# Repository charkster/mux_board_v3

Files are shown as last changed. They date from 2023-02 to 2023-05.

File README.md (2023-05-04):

# mux_board_v3
Custom PCB with SAMD21 QT PY controlling TWO ADG1606BRUZ 16 input muxes!

**--> UPDATED design available: [mux_board_v5](https://github.com/charkster/mux_board_v5) <--**

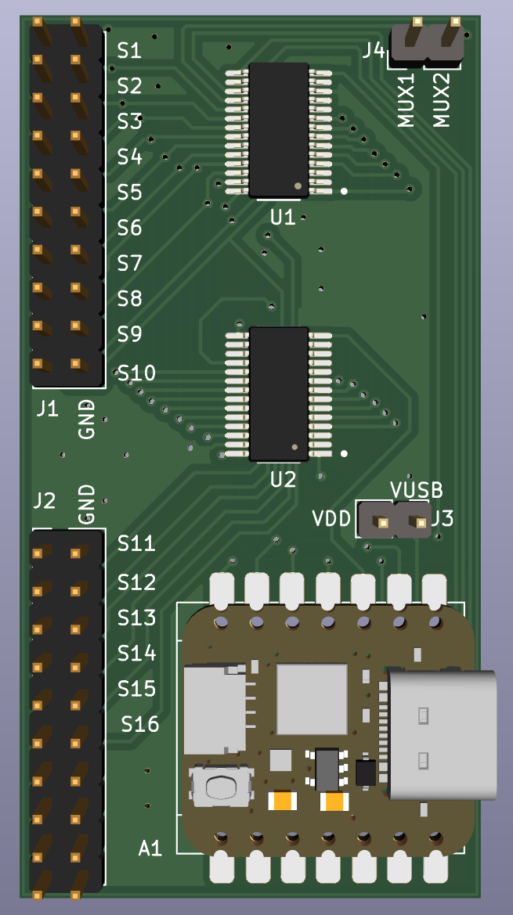
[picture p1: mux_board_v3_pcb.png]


Check-out my **PDF** [schematic](https://github.com/charkster/mux_board_v3/blob/main/mux_board_v3_schematic.pdf) !!

The SAMD21 QT PY can be  programmed with the qt_py_samd21-usbtmc.uf2 file (drag-n-drop) and has the same USBTMC commands that my [Mux Board V1](https://github.com/charkster/mux_board_v1) had. Here is the list:

**MUX1:EN 1** # enable MUX1, a zero will disable the mux

**MUX1:SEL 1** # select S1 input, values 1 through 16 are valid

**MUX1:EN?** # this query returns the state of MUX1

**MUX1:SEL?** # this query returns the presently selected input

***RST** # disables all MUX enables

***IDN?** # returns valid commands and this URL

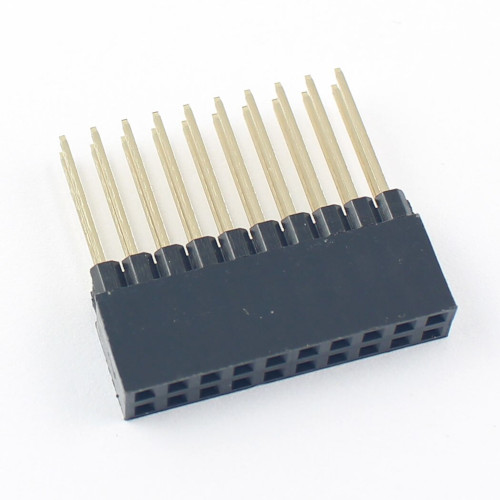
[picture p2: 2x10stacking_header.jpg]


2x10 2.54mm stacking headers can be found on [Aliexpress](https://www.aliexpress.us/item/2251832794527968.html?gatewayAdapt=glo2usa4itemAdapt&_randl_shipto=US)

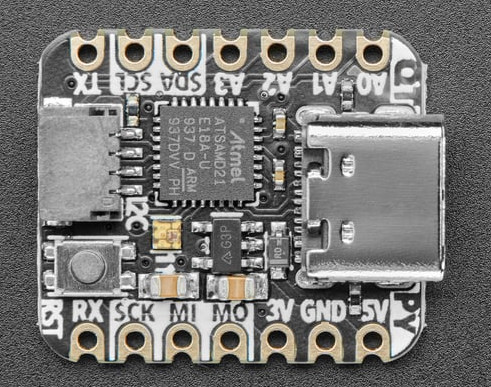
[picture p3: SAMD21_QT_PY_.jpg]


SAMD21 QT PY and ADG1606BRUZ ICs can be found on Digikey/Mouser.

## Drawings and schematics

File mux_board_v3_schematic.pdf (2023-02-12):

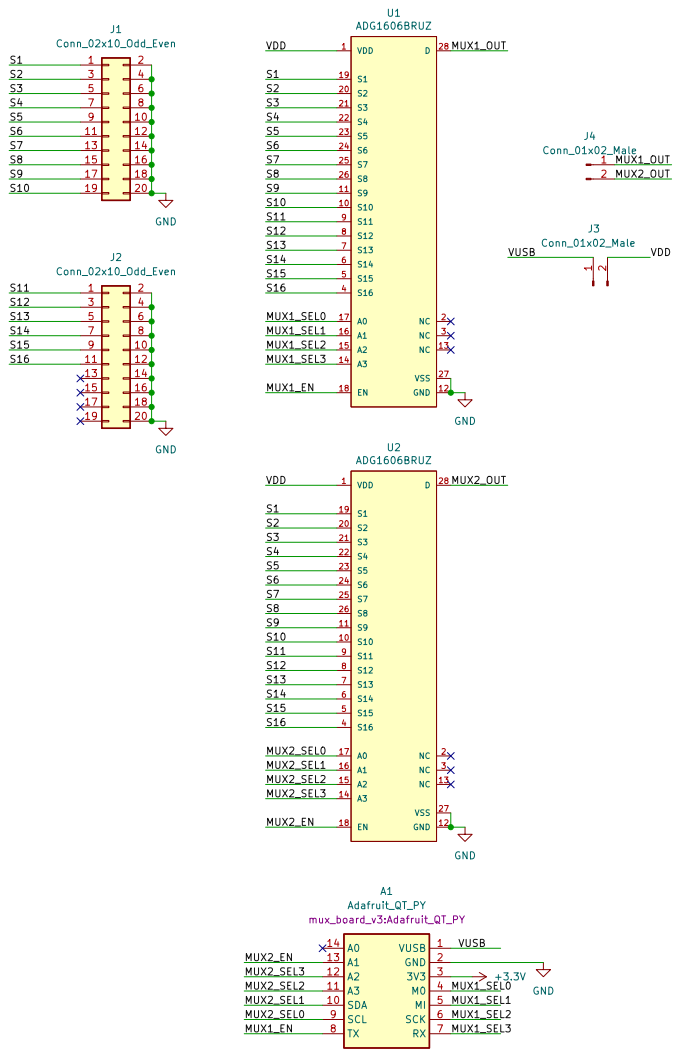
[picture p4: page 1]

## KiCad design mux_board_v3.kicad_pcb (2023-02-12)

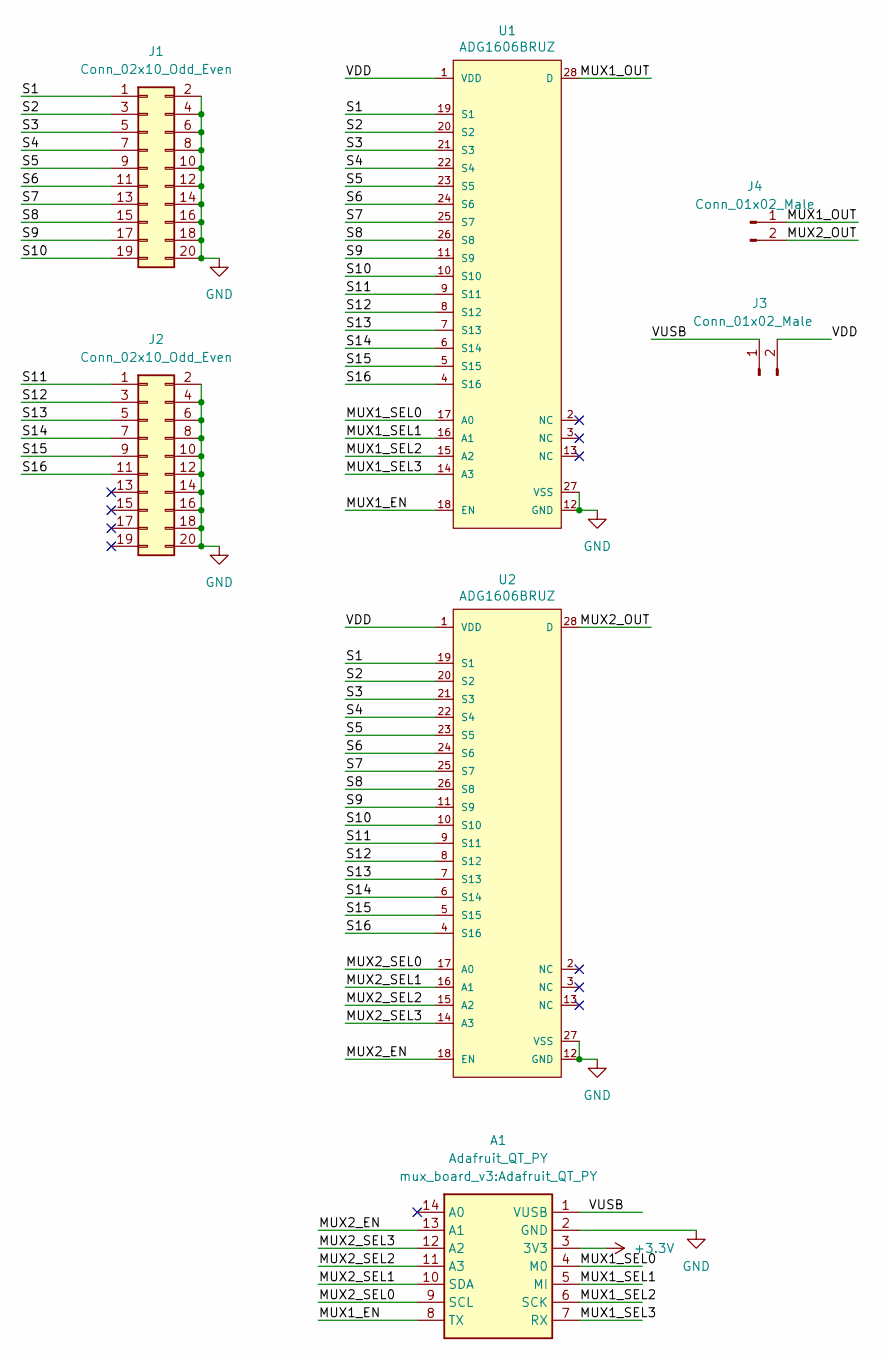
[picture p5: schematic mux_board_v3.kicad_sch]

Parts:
A1: Adafruit_QT_PY
J1, J2: Conn_02x10_Odd_Even; PinHeader_2x10_P2.54mm_Vertical
J3, J4: Conn_01x02_Male; PinHeader_1x02_P2.54mm_Vertical
U1, U2: ADG1606BRUZ; Analog_Devices-RU-28-0-0-IPC_A; mouser part number 584-ADG1606BRUZ; digikey description IC MULTIPLEXER 1 X 16 28TSSOP

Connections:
+3V3: A1.3 (3V3)
/MUX1_EN: A1.8 (TX), U1.18 (EN)
/MUX1_OUT: J4.1, U1.28 (D)
/MUX1_SEL0: A1.4 (M0), U1.17 (A0)
/MUX1_SEL1: A1.5 (MI), U1.16 (A1)
/MUX1_SEL2: A1.6 (SCK), U1.15 (A2)
/MUX1_SEL3: A1.7 (RX), U1.14 (A3)
/MUX2_EN: A1.13 (A1), U2.18 (EN)
/MUX2_OUT: J4.2, U2.28 (D)
/MUX2_SEL0: A1.9 (SCL), U2.17 (A0)
/MUX2_SEL1: A1.10 (SDA), U2.16 (A1)
/MUX2_SEL2: A1.11 (A3), U2.15 (A2)
/MUX2_SEL3: A1.12 (A2), U2.14 (A3)
/S1: J1.1, U1.19 (S1), U2.19 (S1)
/S2: J1.3, U1.20 (S2), U2.20 (S2)
/S3: J1.5, U1.21 (S3), U2.21 (S3)
/S4: J1.7, U1.22 (S4), U2.22 (S4)
/S5: J1.9, U1.23 (S5), U2.23 (S5)
/S6: J1.11, U1.24 (S6), U2.24 (S6)
/S7: J1.13, U1.25 (S7), U2.25 (S7)
/S8: J1.15, U1.26 (S8), U2.26 (S8)
/S9: J1.17, U1.11 (S9), U2.11 (S9)
/S10: J1.19, U1.10 (S10), U2.10 (S10)
/S11: J2.1, U1.9 (S11), U2.9 (S11)
/S12: J2.3, U1.8 (S12), U2.8 (S12)
/S13: J2.5, U1.7 (S13), U2.7 (S13)
/S14: J2.7, U1.6 (S14), U2.6 (S14)
/S15: J2.9, U1.5 (S15), U2.5 (S15)
/S16: J2.11, U1.4 (S16), U2.4 (S16)
/VDD: J3.2, U1.1 (VDD), U2.1 (VDD)
/VUSB: A1.1 (VUSB), J3.1
GND: A1.2 (GND), J1.2, J1.4, J1.6, J1.8, J1.10, J1.12, J1.14, J1.16, J1.18, J1.20, J2.2, J2.4, J2.6, J2.8, J2.10, J2.12, J2.14, J2.16, J2.18, J2.20, U1.12 (GND), U1.27 (VSS), U2.12 (GND), U2.27 (VSS)

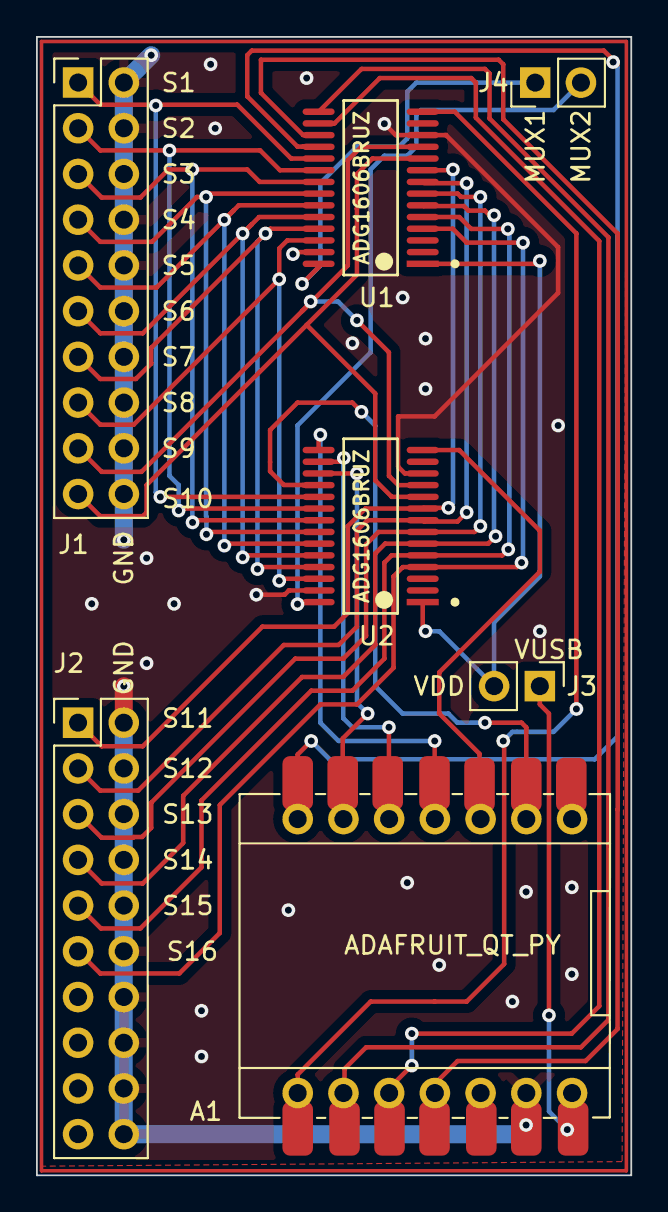
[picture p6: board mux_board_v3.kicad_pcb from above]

Board: 2 copper layers, 33.0 x 63.2 mm, 7 parts (0 on the bottom side), 31 nets.

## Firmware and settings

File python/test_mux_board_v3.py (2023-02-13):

import pyvisa
rm = pyvisa.ResourceManager('@py')
print(rm.list_resources())
samd21 = rm.open_resource('USB0::51966::16384::123456::0::INSTR')
print(samd21.query("*IDN?"))
print(samd21.query("MUX1:SEL?"))
samd21.write("MUX1:SEL 16")
print(samd21.query("MUX1:SEL?"))
print(samd21.query("MUX1:EN?"))
samd21.write("MUX1:EN 1")
print(samd21.query("MUX1:EN?"))
print(samd21.query("MUX2:SEL?"))
samd21.write("MUX2:SEL 15")
print(samd21.query("MUX2:SEL?"))
print(samd21.query("MUX2:EN?"))
samd21.write("MUX2:EN 1")
print(samd21.query("MUX2:EN?"))
samd21.write("*RST")
print(samd21.query("MUX1:SEL?"))
print(samd21.query("MUX1:EN?"))
print(samd21.query("MUX2:SEL?"))
print(samd21.query("MUX2:EN?"))

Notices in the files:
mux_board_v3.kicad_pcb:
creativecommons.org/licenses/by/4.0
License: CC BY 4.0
